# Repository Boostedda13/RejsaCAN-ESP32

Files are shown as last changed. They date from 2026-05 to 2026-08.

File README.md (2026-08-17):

# RejsaCAN

RejsaCAN is a 3x5 centimetre small ESP32 or ESP32-S3 based board aimed at car use that I put together for my own use in my assorted crazy car projects. The board has an onboard CAN interface and can be powered directly from the car (5-24V). It also includes the option to auto shutdown so not to drain the car battery. This is especially important if you have it plugged in to a car OBD2 connector since these always supply constant 12V power to the connector, even when the car is parked and turned off.

There is no bespoke code for the board apart from pin definitions, it's just a piece of universal hardware, but by using easy to use open source Arduino libraries it can be made to interface not only to various CAN buses, Network/Wifi and Bluetooth but to numerous sensors and other peripherals using the ESP32's built in interfaces.

You can assemble your own board if you want, you find schematics, Gerber files and bill of materials in the <a href=Schematics>schematics folder</a>. I currently have a few extra boards so if you need one or more factory assembled boards you can always contact me at magnust@gmail.com.
  
### Nice review and get started guide at cnx-software  
  
https://www.cnx-software.com/2023/05/12/rejsacan-esp32-s3-can-bus-board-arduino-car-hacking/  
  
### Navigate  
  
- <a href=./>Main page (this page)</a>  
 
- <a href=Projects%20and%20ideas>Fun projects and ideas</a>  
 
- <a href=Schematics>Schematics</a>

- <a href=Code%20Examples>Code examples</a>
 
- <a href=Tips%20to%20setup%20IDE%20and%20get%20started>Links to some different CAN libraries and tips to get started</a>  
  
-  <a href=3dprint>Examples of 3D printable housings</a>  

-  <a href=Auxiliary%20boards>Some odd auxiliary boards I made to mount an OBD2 connector, display, thermal cam...</a>  

<hr>
  


## Pinout  
  
See complete pinout.h https://github.com/MagnusThome/RejsaCAN-ESP32/blob/main/Schematics/

S3 rear

## Schematics

click to get full schematics



## The board is based around an ESP32 or ESP32-S3 chip

The ESP32-S3 is a very nice and capable chip that supports a mind boggling range of different communication standards and hardware auxiliaries making it a very versatile "hub" for shuffling data between different systems.  

- SPI bus
- I2C bus
- BLE (Bluetooth 5)
- Wifi (both as AP or client)
- Networking, everything from simple http, mqtt, ajax, ntp to running a full webserver on it with a user interface
- USB port (serial in/out and also OTG as virtual keyboard, wireless storage...)
- Analog input, PWM or analog output

## Examples

- Read CAN data and send back CAN packets to control the car (set to sport mode as default, lock doors when driving away, this is one of my current projects)
- CAN to BLE or network/Wifi bridge
- CAN interface for sniffing CAN bus with for example SavvyCAN
- Read I2C/SPI/analog sensor data and write to CAN bus for CAN bus based data loggers
- Publish live telemetric data on internet from Racechrono (I'm starting this project now)
- Drive alarm beeper or LED to show status of CAN data (like my small project Money Shift Saver and also low oil pressure warning)
- Drive high power peripherals using a driver board
- Translate CAN data between two CAN buses (like my small project Current Gear HUD here on github)

- I have already made a connector board to attach the RejsaCAN on the back of the commonly available small ILI9341 touch screen.

## Ideas for peripherals



- IR camera sensor arrays (MLX90xxx or AMG8833) to log tire, brake, drivetrain temperatures over BLE to Racechrono or CAN based loggers (like my project RejsaRubberTrac https://github.com/MagnusThome/RejsaRubberTrac)  
- Laser based TOF distance sensor to log suspension travel (I did this too with RejsaRubberTrac)  
- SPI or I2C based color displays to show CAN bus data like IC intake or oil temps or alarms  
- SPI or I2C based color displays to show live telemetric data fetched over BLE from Racechrono  
- A second CAN port  
- Driver board to drive high power items  
- Step motor drivers  
- Multiple input analog or digital boards  
   
## One of the 3D printed housings with OBD2 connector I've made


## Or just the board and screw terminals


# CAN interface

You can hook the board up straight to the car's OBD2 port or attach it directly to any CAN bus. You just need to connect the four wires. 12V power, ground, CAN high and low. There is of course a bus termination resistor on the board, it can be disabled if not needed by cutting a pcb trace and optionally mounting a pin header and jumper.

# Supply requirements (v3.5)

**Feed this board from a fused accessory circuit downstream of the vehicle's own
load-dump suppression. Do not hard-wire it upstream of a battery master / kill switch.**

That is not boilerplate, it is the condition the front end is designed to. The board is
rated **5-24 V** with a 33 V DC ceiling, which covers a 12 V system running at 14 V,
a 24 V jump start for 60 s, regulator failure at 18 V for 60 min, reverse polarity, and
ISO 7637-2 pulses 1, 2a, 3a and 3b. The clamp is a 33 V bidirectional TVS at the
connector, so a *suppressed* load dump (35 V for up to 400 ms, which is what a modern
alternator produces) is survived on voltage rating alone.

An **unsuppressed** load dump is a different event: 79-101 V for 40-400 ms, carrying
20-52 J. Opening a battery master switch with the engine running produces exactly that.
No discrete TVS of any package size absorbs it -- a 3 kW SMC part is worth about 3 J.
Surviving that case needs a series surge stopper (LTC4364 class) and roughly 150 mm2 of
board this design does not have. Since RejsaCAN is aimed at motorsport, where kill
switches are common, this restriction is the trade that was made deliberately.

24 V *systems* are out of scope. Their suppressed load dump is 58 V, which no clamp
below 58 V standoff survives, and a 60 V standoff part clamps near 97 V.

# Functionality

The idea was to make an as small as possible CAN + ESP32 board with as many cool and useful "good to have" functions as possible included. You know as well as I do that when tinkering around you suddenly get a new idea and need x or y :-D 

## Auto shutdown

When the engine is running and charging the car battery the incoming voltage used to power the board is a little bit higher than when the engine is stopped. This can be used to automate board shutdown so not to drain the car battery. As default the on board DC-DC power circuit will shutdown the whole board when the power voltage is below the "engine is running" threshold and boot up the board when it is above. But you can run the board in a number of other ways too, for example using ESP32 sleep mode, waking it and putting it to sleep depending on CAN traffic, voltage level from the car, delays and so on.

- An output (FORCE_ON GPIO17) can be pulled high to keep the board running even if the car voltage drops below the threshold (instead of disabling the auto shutdown fully on the pcb by shorting the "ALWAYS ON" bridge). The ESP32 can keep this pin high even during sleep.

- A digital input (SENSE_V_DIG GPIO08) monitors if the car voltage is above or below the "engine running" threshold. This can both be used to trigger waking the board from sleep or just as a simple check if the engine is charging the car battery or not.  

- The voltage from the car can be monitored using analog input (SENSE_V_ANA GPIO9) to check not only charging level but also battery discharge level when parked, health of charging, health of battery, detect large loads being switched on or off in the car and so on.

- The CAN data input (CAN_RX GPIO13) can also be used to trigger waking up the board from sleep as soon as CAN traffic is detected.

Either one can just let the board turn on and off with the auto shutdown hardware circuitry straight out of the box or you can run it in combination with software. For example, when the car voltage rises and the board boots you can pull FORCE_ON high to make sure the board keeps running even if there is a drop of voltage, for example due to red light start/stop functionality in the car or modern cars turning down battery charging even when driving. Then you just monitor either the threshold with SENSE_V_DIG or set your own thresholds using SENSE_V_ANA and then add your own timer delays or whatever. And of course, you can use CAN to check if the car is stopped in a multitude of ways, rpm, speed, gear...

### Fine tuning on/off voltage thresholds  

If your car has a more modern battery type than the old acid/led type or if it does the battery charging slightly different you might want to adjust the on/off voltage thresholds. If you keep R5 as 33k and adjust R4 you can get these switch-on and -off voltages:

| **R4** | **Turn on at** | **Turn off at** |
|---:|---:|---:|
| 91k | 13,7V | 13,0V |
| 90k | 13,6V | 12,9V |
| 89k | 13,5V | 12,8V |
| 88k | 13,4V | 12,7V |
| 87k | 14,3V | 12,6V |
| 86k | 13,2V | 12,5V |
| 85k | 13,1V | 12,4V |

### 24V vehicles

For 24V vehicles you can change the on/off voltage threshold by soldering on a resistor at the empty "ADJUST" position. I don't know what voltages one can expect in these vehicles while charging and not charging the battery so I have no idea what an appropriate resistor value should be there. 

matrix power scenarios  

## "Good to haves"

### Three on board LEDs  

- Green power LED that shows if the board is turned on or not. If using the auto shutdown the green LED (and the board) will be turned on and off depending on if the car voltage is over or under the auto start/shutdown threshold.

- Blue LED to use for anything you fancy (BLUE_LED GPIO10) (this one is red on some boards due to the blue led being out of stock lately)
- Yellow LED to use for anything (YELLOW_LED GPIO11)

### Extra UART RX/TX

The ESP32-S3 has a built in USB port for uploading firmware, OTG support(!) and general communication. But on the board's rear there are breakout pads for a second UART (TXD0 and RXD0) so you can use this as a serial port and the board's USB port for other tasks like JTAG or OTG, acting as a peripheral keyboard, mouse, wireless storage and so on.

### 3V3 HIGH DRIVER

The GPIO pins on the ESP32-S3 can, in addition to general digital circuitry, also drive 10-20mA loads like LEDs and other smaller loads. But on the RejsaCAN board there is an added more powerful driver circuit that can drive slightly larger loads of a few hundred mA at 3,3V. This can be used for different things like powering external sensors or a small display that you want to be able to shutdown fully to minimize power consumption while in sleep mode for example. This 3V3_SWITCHED output is controlled by HI_DRIVER (GPIO21). The ESP32-S3 can keep this on or off when in sleep mode.

There is also a 3,3V power output pad in the row of connection pads on the board that is turned on whenever the board is running. Keep in mind that this is _not_ a 3V3 input to drive the board, it is only an output to drive external I2C, SPI and other sensors.

### SD card reader

The ESP32-S3 has an SD micro card reader on the rear of the pcb. It is connected to SPI and select SD_CARD (GPIO45)

### Other general IO pins
  
All the GPIOs found on the row of connector pads are general purpose. They can be PWM, analog, digital in/out whatever, special protocols driving or reading most things you can think of. But for ease of use for me with occasional lousy memory I have marked some default uses:  
  
I2C SDA  (GPIO1)  (A0)  
I2C SCL  (GPIO2)  (A1)  
GND  
3V3  
  
SPI MISO / MTDI  (GPIO41)  
SPI CLK  / MTCK  (GPIO39)  
SPI MOSI / MTDO  (GPIO40)  
  
General  (GPIO12)  
General  (GPIO48)  
General  (GPIO47)  
High driver switched output max 500mA  (GPIO21)  

On the rear side of the pcb you can get to a few extra pins but it's not possible to solder pin headers here due to the esp-module being on the other side of the board where these pads are.  
  
General  (GPIO6)  (A5)  
General  (GPIO7)  (A6)  
General  (GPIO15)  
General  (GPIO16)  
MTMS  (GPIO42)  
PROG  (GPIO0)  
JTAG_ENABLE  (GPIO3)  
TXD0   
RXD0  

### CAN bus

As mentioned earlier the CAN_RX (GPIO13) can wake the ESP32-S3 from sleep whenever any traffic is seen on the CAN bus.

To minimize power draw when not using the CAN bus, for example not listening to the bus to detect traffic to wake the ESP32 from sleep mode, the CAN transceiver can be put in standby mode by pulling CAN_RS (GPIO38) high. The ESP32-S3 can keep this pin high even when in sleep mode reducing the complete boards power draw to an absolute minimum.

The rise time of the CAN transceiver chip can be changed pulling CAN_RS (GPIO38) low. Default is keeping the pin unmodified in high impedance state for an optimal not-to-fast rise time setting. See specs for the transceiver chip SN65HVD230DR.

### JTAG

You can either run JTAG over the USB port or optionally keep the USB port free by connecting your JTAG hardware to MTDI, MTDO, MTCK and MTMS on the board. Note that MTMS is only available on the board's rear. The other are available in the row of connecting pads. Incidentally the MTDI, MTDO and MTCK are the same as the SPI default pins.

To enable JTAG mode you need to pull the JTAG_ENABLE pad, found on the rear of the board, high or low at boot.

### Board version

On v3.x boards you can programmatically check what version of the board your code is running on and adjust accordingly for the small changes that have been made on the boards. Set GPIO4 and GPIO5 to input pullup and check if the inputs are high or low.

- v3.1 = GPIO4 low and GPIO5 high  
- v3.2 = GPIO4 high and GPIO5 low  

### Changes

#### from v3.1 to v3.2

- Added RS control of the CAN chip to set both standby mode and faster rise times
- Added better over voltage protection on power from the car
- Upgraded over voltage protection on USB power
- Enabling ALWAYS_ON is now done by shorting two clearly marked pads on the rear of the board
- An added empty spot for resistor R19 ADJUST which can be added to lower the start/stop voltage threshold for the board
- For panic situations when you need more pins ;-) the GPIO6, GPIO7, GPIO15 and GPIO16 are available as unmarked pads but only on the rear of the board
  
#### From v2.3 to v.2.4
  
- Upgraded over voltage protection on USB power  

#### From v2.4 to v.2.5 and 3.2 to 3.3
  
- DC-DC converter supports 24V input. The auto switch on/off threshold can be changed by changing two resistor values.  

## Power consumption  
 
At 14V the complete board draws *on average* roughly:  
- Bluetooth turned on but no connections = 16mA (+ 4mA for power LED)
- Wifi turned on as AP with local web server but no connections = 46mA (+ 4mA for power LED)
- No wifi or Bluetooth = 14mA (+ 4mA for power LED)
- Sleep = 3mA (+ 4mA for power LED). Note that the CAN transceiver is fully active and the DC-DC buck converter probably has some idle draw also.
- Sleep and CAN transceiver put in standby = hmmm, must test this, a fraction of a mA is my guess.
   
## Housing

Check out 3D printable housings in the <a href=3dprint>the 3D-print directory</a>. So far I've made one housing where you connect using a cable and another one with an integrated OBD2 connector to plug directly into the car.



transparent-case-1

small-housing(0)
  


## Connecting the board

When not using the housing with an integrated OBD2 connector or the screw terminals as seen in the picture above I've used a widely available OBD2 splitter cable (flat cable) that has one male and two female connectors. I hook up the male connector to the car, cut off one female connector and wire the remaining pig tail cable into the RejsaCAN board and one female connector is then free for other equipment to hook up to the car.

Picture showing what wires to use but please measure your cable and don't trust all these splitter cables to be 100% identical. (the second female splitter connector is not visible in pic)
   
OBD2 splitter pinout
 
small-housing(3)
 
small-housing(2)

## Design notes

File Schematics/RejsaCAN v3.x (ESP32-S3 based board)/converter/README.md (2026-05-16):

# EasyEDA Standard → Fusion/Eagle 9.x converter

Custom converter built to translate the RejsaCAN v3.4 EasyEDA Standard
schematic (`RejsaCAN v3.4 - Schematic.json`) into a Fusion-importable
Eagle 9.x `.sch` file. Fusion Electronics has no native EasyEDA
importer; the official-blessed paths (EasyEDA → Altium → Fusion, or
EasyEDA → KiCad) all failed in different ways, so we built this.

## Files

| File | Purpose |
|---|---|
| `easyeda_parser.py` | Parses the tilde/caret/hash-encoded EasyEDA JSON into clean Python dataclasses; also resolves nets via union-find and splits wires at T-intersections. |
| `eagle_emitter.py` | Synthesises an Eagle 9.x XML schematic (library + parts + sheet + nets) from the parsed structure. |
| `convert.py` | CLI: `python convert.py <input.json> [-o output.sch] [--summary]` |

Run from this `converter/` directory:

```
python convert.py "..\RejsaCAN v3.4 - Schematic.json" -o "..\RejsaCAN v3.4.sch"
```

## EasyEDA Standard JSON format (reverse-engineered)

The schematic file is a JSON wrapper around a list of "shape" strings,
each tilde-delimited. Multi-piece shapes use `#@$` between sub-pieces
and `^^` between sub-fields within a piece.

Top-level structure:
```
{
  "editorVersion": "6.5.39",
  "docType": "5",
  "title": "...",
  "schematics": [
    {
      "dataStr": {
        "shape": [ "<shape1>", "<shape2>", ... ]
      }
    }
  ]
}
```

### Shape prefixes seen in this file

| Prefix | Count | Meaning |
|---|---|---|
| `LIB` | 66 | Component instance (incl. 1 page-frame instance) |
| `W` | 144 | Wire polyline (`W~x1 y1 x2 y2 [x3 y3 ...]~color~...`) |
| `J` | 74 | Junction dot (`J~x~y~radius~color~gid~lock`) |
| `F` | 90 | Net label / flag (anchor + text + decoration) |
| `O` | 11 | No-connect marker (X-shape glyph at a coord) |
| `T` | 2 | Free text annotation |

### LIB (component) internals

A LIB shape has the header followed by `#@$`-separated sub-pieces:
```
LIB ~ x ~ y ~ propBlob ~ rotation ~ importFlag ~ uuid ~ ...
  #@$ T~P~...~designator~...     (designator)
  #@$ T~N~...~value~...           (value/name)
  #@$ R~bx~by~bw~bh~...           (body rectangle, decorative)
  #@$ P~display~elec~pinNum~px~py~rot~gid~lock^^portX~portY^^pathDef^^pinNameField^^pinNumField^^...
  #@$ ... (more pins)
```

**propBlob** is backtick-delimited key/value pairs:
```
package`HDR-M-2.54_1X2`Supplier Part`C124375`Supplier`LCSC`...`
```

**Pin** sub-piece pieces (joined by `^^`):
1. Header: `P~show~0~<pinNum>~<x>~<y>~<rot>~<gid>~<lock>`
2. Port: `<portX>~<portY>` — **this is the wire-attach coordinate**
3. Path: `M ... h ...` — pin line drawing
4. Pin name field: `1~<x>~<y>~0~<text>~start~~~<color>`
5. Pin number field
6. Optional clock/dot decorations

### F (net label) internals

```
F~part_netLabel_<style>~<x>~<y>~<rot>~<gid>~~<lock>
  ^^<anchorX>~<anchorY>
  ^^<netName>~<color>~<textX>~<textY>~...~<flag_id>
  ^^PL~<polyline...>  (label flag graphics, decoration only)
  ^^...
```

The **net name** is the first sub-field of the third `^^`-piece. The
**anchor** in the second piece is the connection point (where the flag
"points to").

### Coordinate system

EasyEDA Standard uses **10-mil units** (1 unit = 0.254 mm) with **Y
positive-down**. Eagle uses millimetres with Y positive-up. Conversion:

```
eagle_mm_x = easyeda_x * 0.254
eagle_mm_y = -easyeda_y * 0.254
```

The 1149 × 806 sheet frame is exactly A4 (291.85 × 204.72 mm) at this
scale.

## Architecture

### Stage 1 — parse → intermediate

`easyeda_parser.parse(path)` returns an `EasyEDASchematic`:

```python
@dataclass
class EasyEDASchematic:
    title: str
    parts: list[Part]              # 65 components (page frame stripped)
    wires: list[WireSegment]       # 247 segments after T-intersection split
    junctions: list[Junction]      # 74 junction markers
    labels: list[NetLabel]         # 90 named-net labels
    no_connects: list[NoConnect]   # 11 NC markers
    pin_to_net: dict[(des, pin#), net_name]
    nets: dict[net_name, list[(des, pin#)]]
    wire_to_net: dict[wire_idx, net_name]
```

Net resolution uses **union-find on coordinate keys** (quantised to
0.01 EasyEDA units). All connection points (pin ports, wire endpoints,
junction coords, label anchors) get added; wires union their two
endpoints; labels with the same name across disjoint clusters union
those clusters (named global nets like `GND`, `+3V3`).

### Stage 2 — emit Eagle 9.x XML

For each part: synthesise one symbol + one deviceset (no dedupe in v1;
65 unique symbols/devicesets, no package mapping). Then emit a single
sheet with instances + nets.

### Net partitioning

A single Eagle `<net>` may contain multiple `<segment>` elements; each
segment must be a graph-connected wire group. Bridging across
segments happens via shared label name. The emitter does its own
union-find per net (over wire endpoints only — labels do **not** bridge
segments) and emits one `<segment>` per connected component, attaching
pinrefs / labels / junctions to whichever component contains their
coord.

## Bugs we hit and fixes

These are the gotchas, in order of severity, all encountered while
iterating against Fusion's ERC. Document them so future-you doesn't
re-discover them.

### 1. T-intersection blindness (catastrophic)

EasyEDA freely allows a wire's endpoint to terminate in the **middle**
of another wire's segment, marked with a junction dot. My initial
union-find merged only on exact endpoint equality, so it missed every
T-intersection — fragmenting what should be one net into many. **Net
count dropped from 100 → 63 once T-splitting was added.**

Fix: `_split_wires_at_intersections()` in `easyeda_parser.py`. For
every wire, find any "interesting" coord (other wire endpoints,
junctions, pin ports, labels) lying on its interior, and replace the
wire with multiple sub-segments through those points. Restricted to
axis-aligned wires (EasyEDA schematics are virtually always
axis-aligned).

### 2. "Segment of net X has fallen apart" (37 errors)

First-pass emitter dumped all wires of a net into one
`<segment>`. Eagle requires each segment to be a graph-connected wire
group. Fix: `_emit_partitioned_nets()` runs union-find per net (over
wires only, not labels) and emits one segment per component.

### 3. Labels attached directly to pins ("floating pinref")

EasyEDA permits a net label flag to attach directly to a pin's port
with no explicit wire drawn. Eagle considers a pinref "floating" if
its coord has no wire endpoint, junction, or sibling pin
there. Fix: emit a 1.27 mm stub wire from each label-only-attached
pinref's coord into space (always +x direction; cosmetic-only).

### 4. Missing junction at pin + 2 wires meeting

Eagle's "missing junction" warning fires not just for 3+ wire endpoints
meeting, but also for **1 pin + 2 wire endpoints** meeting at a coord
(visually a T at the pin). Fix: junction emission rule is
`(wire_endpoints + pinref_count) >= 3 OR pinref_count >= 2`. The
second clause also handles direct pin-on-pin overlaps (the
`R10.1+R9.1`, `R15.1+YELLOW.2`, etc. cases).

### 5. Junctions created from EasyEDA coords were under-emitted

Initial logic only emitted junctions where EasyEDA originally had
one. After T-splitting, **new** multi-endpoint coords appear that
EasyEDA never marked (they were on the interior of a wire before
splitting). Fix: emit junctions self-driven from the segment's wire
endpoint counts, not from `c["juncs"]`.

### 6. Synthesised body boxes colliding with neighbours

For parts where all pins lie on a single axis (most 2-pin SMDs, header
strips, the 13-pin SD-CARD, the 16-pin USBC), the original "body" was
some EasyEDA glyph in a particular position. Our placeholder
rectangle, placed perpendicular to the pin line, ended up overlapping
neighbour parts' pins on the sheet. This triggered "Net X overlaps
pin" / "Pins overlap" warnings.

Fix tried in stages:
- Shrink degenerate-axis body to 1.27 mm thickness — reduced collisions but didn't eliminate edge-touches.
- Drop body wires entirely for degenerate-axis parts (59 of 65) — eliminates warnings but loses cosmetic body shape.
- Switch all pin lengths from `short` (2.54 mm) → `point` (0 mm) — pins can no longer extend to overlap anything.

### 7. Pin rotation pointing into colinear neighbours

For multi-pin colinear parts (SD-CARD's 13 pins all at same x), the
original `infer_pin_rot` used pin-bbox centre — which equalled each
pin's x — so adjacent pins got opposite vertical rotations and their
drawn stubs hit each other's connection points. Fix:
`infer_pin_rot_from_body` chooses rotation by the body edge each pin
is closest to (or outside of), so all pins on one face of a body
rotate the same way.

### 8. Eagle name strictness

Designators like `SD-CARD` (hyphen) and all-caps descriptive names
like `BLUE`, `POWER`, `GPIO`, `I2C` were preserved per user request.
Fusion 9 accepted them all; if a future version of Eagle/Fusion
rejects, run them through `sane_name()` with a stricter character set.

## Final state

- 65 parts, 63 nets, 117 segments, 67 junctions, 534 wires (incl. body
  wires for the 6 chip-style parts and synthesised stubs).
- ~22 ERC warnings remaining, all by design:
  - **19 single-pin nets** — 11 are EasyEDA NC markers (intentional);
    8 are named ESP32 pins not broken out in this design (GPIO6/7/15/16,
    JTAG_ENABLE, MTMS, RXD, TXD). Approve in Fusion's ERC.
  - 0–3 residual cosmetic edge cases.

## Limitations / known cosmetic issues

- **Symbol art is placeholder.** Passives show as connection points
  only (no zigzag/plate). Multi-axis-spread chips show as bounding
  rectangles. Connectivity is correct; cosmetics need manual library
  swap if visual fidelity matters.
- **No PCB output** (`.brd`). The deviceset has no package mapping —
  every part is "schematic-only". Forward-annotate from Fusion to a
  new board if you want to lay out.
- **No multi-sheet support.** Source file has 1 sheet; multi-sheet
  parsing exists in `parse()` but the emitter ignores sheets > 0.
- **NCs handled as single-pin nets**, not Eagle no-connect markers
  (Eagle 9 has no first-class `<no_connect>` element — the standard
  workaround is just an unconnected pin).
- **Stub wires are always +x direction** for label-only-attached pins.
  Could be cosmetically improved by aiming toward where the label
  text sits.

## Future work

If anyone needs to extend this:

- **KiCad emitter** as a peer to `eagle_emitter.py`. The intermediate
  `EasyEDASchematic` is format-agnostic; KiCad's S-expression schema
  is simpler than Eagle's XML. ~1 hour of work.
- **Symbol dedupe.** Currently 65 unique symbols/devicesets. A
  componentUuid-based key would collapse duplicates (all R0402s share
  one symbol).
- **Real symbol art.** Parse the `R~`, `PT~` (path), `PL~` (polyline),
  `E~` (ellipse) sub-pieces inside each LIB and emit as Eagle wire/
  arc/circle elements within the symbol.
- **Package mapping.** Devicesets currently have no `<package>`
  element. Adding a stub package per part (with pad numbers matching
  pin numbers) would enable forward-annotation to a board.
- **Multi-sheet** when source has > 1 sheet.
- **Bus support.** EasyEDA buses (B-prefix shapes) are not handled.
  This file has no buses so it didn't matter.

## Quickstart for the next person

```bash
cd "Schematics/RejsaCAN v3.x (ESP32-S3 based board)/converter"
python convert.py "../RejsaCAN v3.4 - Schematic.json" --summary
# writes ../RejsaCAN v3.4.sch and prints parts + top nets
```

Open the resulting `.sch` in Fusion Electronics 9.x. Run ERC. Approve
the by-design single-pin warnings. Edit freely.

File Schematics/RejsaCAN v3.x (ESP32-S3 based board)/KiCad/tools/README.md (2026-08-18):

# tools/

Scripts that finished the v3.5 board without the GUI. They run under KiCad's own Python
(`"C:\Program Files\KiCad\10.0\bin\python.exe"`, the only interpreter with `pcbnew`) and operate on
`../RejsaCAN v3.4 - Schematic.kicad_pcb`. Scratch output goes to `tools/out/` (gitignored) or to
`$REJSA_OUT`.

| Script | What it does |
|---|---|
| `miniroute.py NET [--w 0.2] [--via 0.6/0.3] [--layers F,I2,B] [--window x0 y0 x1 y1] [--viacost 120] [--src REF.PAD --dst REF.PAD] [--apply]` | Obstacle-aware grid router for **one connection**: rasterises every copper item that is not on `NET` into per-layer masks inflated by `w/2 + max(clearance of both net classes) + 1 cell`, plus a via mask (all layers, hole-to-hole, edge band), then runs Dijkstra from the smallest island of the net to the largest over F/In2/B with via transitions. Without `--apply` it only writes `<tag>_path_<layer>.png` overlays. With `--apply` it adds the copper, snaps route ends to pad centres, refills zones and keeps a `.bak`. Run it repeatedly for a net with more than two islands. |
| `stitch.py [--grid 4.0] [--minsp 1.2] [--via 0.6/0.3] [--apply]` | GND stitching vias: a fence both sides of the RF trace, a ring around U7's ground pads, and a grid — every candidate filtered by the router's via mask and by outer-layer pour membership, then added all at once so DRC can prune. |
| `drcgate.py TAG [--show type1,type2]` | `kicad-cli pcb drc --severity-all --all-track-errors`, summarised as error/warning counts by type plus the unconnected list. **This is the acceptance test**: apply one change, run it, keep the change only if errors did not rise. |

The router is deliberately not a full autorouter: it knows nothing about the `.kicad_dru` custom
rules beyond net-class clearance, it does not shove, and it will happily route the last connection
through an ugly place if that is the only free one. It exists because the interactive router needs a
GUI session and Freerouting cannot be told to finish a nearly-complete board (see CLAUDE.md).

Things learned the hard way, all encoded above:

- `NETINFO_ITEM.GetNetClass()` returns a bare `SwigPyObject`; use `GetNetClassName()` and read the
  clearance table from the `.kicad_pro` JSON. Getting this wrong routed Battery-class copper at
  0.15 mm and produced 11 clearance errors.
- PIL rasterises to integer pixels, so a shape can end up half a cell short — hence the extra cell of
  inflation. Without it one route landed 0.01 mm inside a pad's clearance.
- A track hugging the board edge leaves a hair-thin GND pour strip outside it (`connection_width`
  0.0004 mm); the edge band keeps tracks ≥ 0.85 mm from the outline so the strip is a real pour or
  nothing.
- Route ends are snapped to pad centres. KiCad's connectivity is shape-based and accepts a track
  ending on a pad edge, but it looks like a mistake and is fragile.

## Schematic tools

The same idea applied to the `.kicad_sch`, used to reorganize the schematic on 18 Aug 2026:

| Script | What it does |
|---|---|
| `schgeom.py` | Parses the schematic (own S-expression parser), builds symbol bounding boxes from `lib_symbols`, pins, labels, wires, visible field texts (real font size + justify), and prints an overlap report. |
| `schclusters.py` | Wired clusters — symbol + wires + labels + junctions joined by geometry. Anything translated as a cluster keeps its connectivity. |
| `schmove.py --apply` | Rigid cluster moves to a target table, editing only the `(at ..)`/`(xy ..)` numbers inside each node's text span (file otherwise byte-identical). |
| `schfix2.py`, `schfix3.py` | The two hand fixes of that pass (label re-pointing; J1's GND flag on a longer wire). |
| `schtext.py --apply` | Auto-placer for Reference/Value texts that collide with symbols, labels or other texts. |
| `netcheck.py save <tag>` / `compare <a> <b>` | **The acceptance test**: `kicad-cli sch export netlist` reduced to pin-groupings, compared before/after (net renames reported separately). Also diff `kicad-cli sch erc` counts. |

Traps met: scripted symbols carry `(unit 0)` — KiCad draws every unit's pins for those; KiCad 10 writes
`(hide yes)` at *property* level, not inside `effects`; EasyEDA-imported fields are 1.69 mm Arial,
left-justified — model both or the placer puts "D10" on top of its own value.

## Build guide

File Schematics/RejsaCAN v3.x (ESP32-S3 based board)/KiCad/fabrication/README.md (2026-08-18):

# fabrication/

Generated manufacturing output for the KiCad board — Gerbers, drill files, position files, BOM
export, renders, STEP. **Nothing in here is a design source.** Everything is reproducible from
`../RejsaCAN v3.4 - Schematic.kicad_pcb`, so the contents are gitignored and only this README is
tracked.

Regenerate without opening the GUI (4-layer set with Protel extensions, which is what JLCPCB expects;
`RejsaCAN_v3.5_gerbers.zip` is the upload):

```bash
cd "Schematics/RejsaCAN v3.x (ESP32-S3 based board)/KiCad"
kicad-cli pcb export gerbers -o fabrication/gerbers/ \
  --layers F.Cu,In1.Cu,In2.Cu,B.Cu,F.Paste,B.Paste,F.Silkscreen,B.Silkscreen,F.Mask,B.Mask,Edge.Cuts \
  --subtract-soldermask --no-x2 --disable-aperture-macros "RejsaCAN v3.4 - Schematic.kicad_pcb"
kicad-cli pcb export drill -o fabrication/gerbers/ --format excellon --drill-origin absolute \
  --excellon-units mm --excellon-zeros-format decimal --excellon-separate-th "RejsaCAN v3.4 - Schematic.kicad_pcb"
kicad-cli pcb export pos -o fabrication/cpl.csv --format csv --units mm --side both --smd-only "RejsaCAN v3.4 - Schematic.kicad_pcb"
kicad-cli pcb render -o fabrication/render_top.png --side top --background opaque --quality basic --width 2400 --height 1900 "RejsaCAN v3.4 - Schematic.kicad_pcb"
kicad-cli pcb render -o fabrication/render_iso.png --perspective --rotate "-35,0,25" --floor --quality high --background opaque --width 2400 --height 1600 "RejsaCAN v3.4 - Schematic.kicad_pcb"
kicad-cli pcb export step --subst-models --force -o fabrication/RejsaCAN_v3.5.step "RejsaCAN v3.4 - Schematic.kicad_pcb"
```

Render notes: `--quality high` in the orthographic top/bottom views paints the board's own drop shadow
onto the floor beside it, which reads as a ghost outline — use `basic` for those and keep `high` for
the perspective view. U7 (LG290P03), J1 (Micro-Fit), USBC1 and SD-CARD1 have no 3D models and render
as pads/outlines.

Upstream's released output for the *fabricated* board is a different thing and lives one directory up
as `RejsaCAN v3.4 - Gerber.zip`. Don't confuse the two: that zip is the board that physically exists,
this directory is whatever the KiCad project currently produces.

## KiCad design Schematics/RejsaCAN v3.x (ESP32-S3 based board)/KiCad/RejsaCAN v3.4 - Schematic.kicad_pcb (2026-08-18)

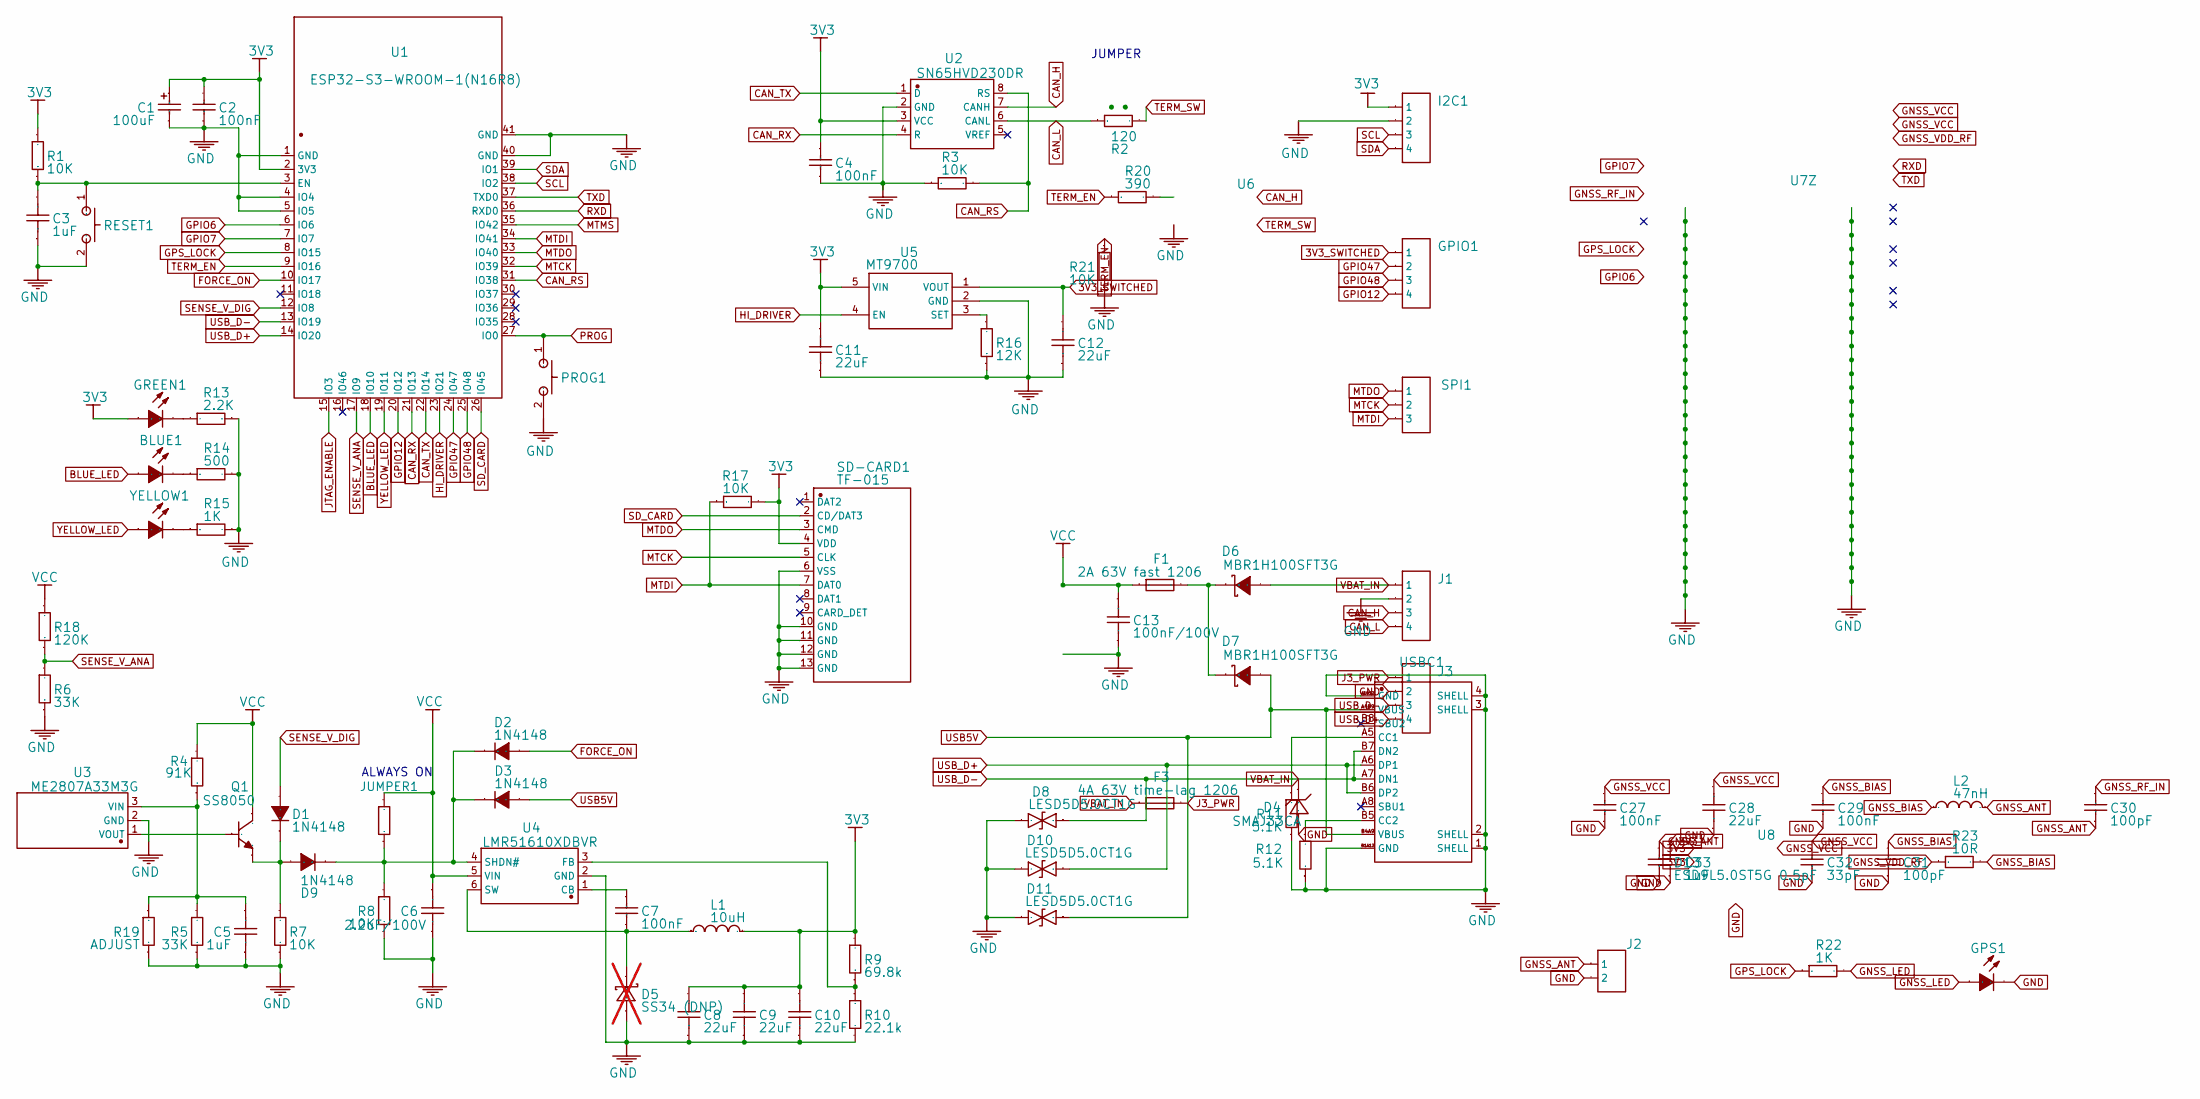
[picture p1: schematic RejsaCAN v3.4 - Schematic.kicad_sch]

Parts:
BLUE1: 19-217/BHC-ZL1M2RY/3T; LED_0603_1608Metric; Manufacturer Part 19-217/BHC-ZL1M2RY/3T
C1: 100uF; CP_EIA-3528-21_Kemet-B; Manufacturer Part TAJB107K006RNJ
C2, C4, C7, C27, C29: 100nF; C_0402_1005Metric; Manufacturer Part CL05B104KO5NNNC
C3, C5, C33: 1uF; C_0402_1005Metric; Manufacturer Part CL05A105KA5NQNC
C6: 2.2uF/100V; C_1210_3225Metric; Manufacturer Part CL32B225KCJSNNE
C8, C9, C10, C11, C12, C28: 22uF; C_0603_1608Metric; Manufacturer Part CL10A226MQ8NRNC
C13: 100nF/100V; C_0603_1608Metric; Manufacturer Part CL10B104KC8NNNC
C30, C31: 100pF; C_0402_1005Metric; Manufacturer Part 0402CG101J500NT
C32: 33pF; C_0402_1005Metric; Manufacturer Part 0402CG330J500NT
D1, D2, D3, D9: 1N4148; D_SOD-323; Manufacturer Part 1N4148WS
D4: SMAJ33CA; D_SMA; Manufacturer Part SMAJ33CA
D5: SS34 (DNP); D_SMA; Manufacturer Part SS34; not fitted
D6, D7: MBR1H100SFT3G; D_SOD-123F; Manufacturer Part MBR1H100SFT3G
D8, D10, D11: LESD5D5.0CT1G; D_SOD-523; Manufacturer Part LESD5D5.0CT1G
D13: ESD9L5.0ST5G 0.5pF; D_0402_1005Metric; Manufacturer Part ESD9L5.0ST5G
F1: 2A 63V fast 1206; Fuse_1206_3216Metric; Manufacturer Part 0466002.NRHF
F3: 4A 63V time-lag 1206; Fuse_1206_3216Metric; Manufacturer Part 1206T4A63V
GPIO1: HDR-M-2.54_1x4; PinHeader_1x04_P2.54mm_Vertical; Manufacturer Part B-2100S04P-A110
GPS1: Blue LED; LED_0603_1608Metric; Manufacturer Part 19-217/BHC-ZL1M2RY/3T
GREEN1: 19-217/GHC-YR1S2/3T; LED_0603_1608Metric; Manufacturer Part 19-217/GHC-YR1S2/3T
I2C1: HDR-M-2.54_1x4; PinHeader_1x04_P2.54mm_Vertical; Manufacturer Part B-2100S04P-A110
J1: Micro-Fit 3.0 4P R/A; Molex_Micro-Fit_3.0_43045-0400_2x02_P3.00mm_Horizontal; Manufacturer Part 43045-0400
J2: U.FL; U.FL_Hirose_U.FL-R-SMT-1_Vertical; Manufacturer Part U.FL-R-SMT-1(10)
J3: JST-XH 4P LTE; JST_XH_B4B-XH-A_1x04_P2.50mm_Vertical; Manufacturer Part B4B-XH-A(LF)(SN)
JUMPER1: -; R_0402_1005Metric; Manufacturer Part DNP
L1: 10uH; L_Sunltec_SLP6028S_6.0x6.0mm; Manufacturer Part SLP6028S100MTT
L2: 47nH; L_0402_1005Metric; Manufacturer Part LQW15AN47NJ00D
PROG1: GT-TC029B-H025-L1N; SW_Push_GSwitch_GT-TC029B; Manufacturer Part GT-TC029B-H025-L1N
Q1: SS8050; SOT-23; Manufacturer Part SS8050
R1, R3, R7, R8, R17, R21: 10K; R_0402_1005Metric; Manufacturer Part 0402WGF1002TCE
R2: 120; R_1206_3216Metric; Manufacturer Part RTT061200FTP
R4: 91K; R_0402_1005Metric; Manufacturer Part 0402WGF9102TCE
R5, R6: 33K; R_0402_1005Metric; Manufacturer Part 0402WGF3302TCE
R9: 69.8k; R_0402_1005Metric; Manufacturer Part 0402WGF6982TCE
R10: 22.1k; R_0402_1005Metric; Manufacturer Part 0402WGF2212TCE
R11, R12: 5.1K; R_0402_1005Metric; Manufacturer Part 0402WGF5101TCE
R13: 2.2K; R_0402_1005Metric; Manufacturer Part 0402WGF2201TCE
R14: 500; R_0402_1005Metric; Manufacturer Part 0402WGF4700TCE
R15, R22: 1K; R_0402_1005Metric; Manufacturer Part 0402WGF1001TCE
R16: 12K; R_0402_1005Metric; Manufacturer Part 0402WGF1202TCE
R18: 120K; R_0402_1005Metric; Manufacturer Part 0402WGF1203TCE
R19: ADJUST; R_0402_1005Metric; Manufacturer Part 0402WGF9102TCE
R20: 390; R_0402_1005Metric; Manufacturer Part 0402WGF3900TCE
R23: 10R; R_0402_1005Metric; Manufacturer Part 0402WGF100JTCE
RESET1: GT-TC029B-H025-L1N; SW_Push_GSwitch_GT-TC029B; Manufacturer Part GT-TC029B-H025-L1N
SD-CARD1: TF-015; microSD_ATOM_MR01A-01211; Manufacturer Part TF-015
SPI1: HDR-M-2.54_1x3; PinHeader_1x03_P2.54mm_Vertical; Manufacturer Part 2.54mm 1x3 header
U1: ESP32-S3-WROOM-1(N16R8); ESP32-S3-WROOM-1_RejsaCAN; Manufacturer Part ESP32-S3-WROOM-1-N16R8
U2: SN65HVD230DR; SOIC-8_RejsaCAN_5.544mm; Manufacturer Part SN65HVD230DR
U3: ME2807A33M3G; SOT-23; Manufacturer Part ME2807A33M3G
U4: LMR51610XDBVR; TSOT-23-6; Manufacturer Part LMR51610XDBVR
U5: MT9700; SOT-23-5; Manufacturer Part MT9700
U6: AQY212GS; SOP-4_3.8x4.1mm_P2.54mm; Manufacturer Part AQY212GS
U7: LG290P03AAMD; Manufacturer Part LG290P03AAMD
U8: RT9013-33GB; SOT-23-5; Manufacturer Part RT9013-33GB
USBC1: GT-USB-7010ASV; USB_C_Receptacle_GT-USB-7010ASV_MergedPins; Manufacturer Part GT-USB-7010ASV
YELLOW1: 19-213/Y2C-CQ2R2L/3T(CY); LED_0603_1608Metric; Manufacturer Part 19-213/Y2C-CQ2R2L/3T(CY)

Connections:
3V3: C1.1, C2.2, C4.2, C8.2, C9.2, C10.2, C11.2, C33.2, GREEN1.1 (A), I2C1.1, L1.2, R1.2, R9.2, R17.2, SD-CARD1.4 (VDD), U1.2 (3V3), U2.3 (VCC), U5.5 (VIN), U8.1 (VIN), U8.3 (EN)
3V3_SWITCHED: C12.2, GPIO1.1, U5.1 (VOUT)
BLUE_LED: BLUE1.1 (A), U1.18 (IO10)
CAN_H: J1.3, U2.7 (CANH), U6.4
CAN_L: J1.4, R2.1, U2.6 (CANL)
CAN_RS: R3.2, U1.31 (IO38), U2.8 (RS)
CAN_RX: U1.21 (IO13), U2.4 (R)
CAN_TX: U1.22 (IO14), U2.1 (D)
FORCE_ON: D2.2 (A), U1.10 (IO17)
GND: C1.2, C2.1, C3.1, C4.1, C5.1, C6.1, C8.1, C9.1, C10.1, C11.1, C12.1, C13.1, C27.1, C28.1, C29.1, C31.1, C32.1, C33.1, D4.2, D5.2 (A), D8.2, D10.2, D11.2, D13.1, GPS1.2 (C), I2C1.2, J1.2, J2.2, J3.2, PROG1.2, R3.1, R5.1, R6.1, R7.1, R8.1, R10.2, R11.1, R12.1, R13.1, R14.2, R15.2, R16.1, R19.2, R21.1, RESET1.2, SD-CARD1.6 (VSS), SD-CARD1.10 (GND), SD-CARD1.11 (GND), SD-CARD1.12 (GND), SD-CARD1.13 (GND), U1.1 (GND), U1.4 (IO4), U1.5 (IO5), U1.40 (GND), U1.41 (GND), U2.2 (GND), U3.2 (GND), U4.2 (GND), U5.2 (GND), U6.2, U7.10 (GND_1), U7.12 (GND_1__1), U7.13 (GND_1__2), U7.24 (GND_1__3), U7.25 (GND_1__4), U7.26 (GND_1__5), U7.27 (GND_1__6), U7.28 (GND_1__7), U7.29 (GND_1__8), U7.30 (GND_1__9), U7.31 (GND_1__10), U7.32 (GND_1__11), U7.33 (GND_1__12), U7.34 (GND_1__13), U7.35 (GND_1__14), U7.36 (GND_1__15), U7.37 (GND_1__16), U7.38 (GND_1__17), U7.39 (GND_1__18), U7.40 (GND_1__19), U7.41 (GND_1__20), U7.42 (GND_1__21), U7.43 (GND_1__22), U7.44 (GND_1__23), U7.45 (GND_1__24), U7.46 (GND_1__25), U7.47 (GND_1__26), U7.48 (GND_1__27), U7.49 (GND_1__28), U7.50 (GND_1__29), U7.51 (GND_2), U7.52 (GND_2__1), U7.53 (GND_2__2), U7.54 (GND_2__3), U7.55 (GND_2__4), U7.56 (GND_2__5), U7.57 (GND_2__6), U7.58 (GND_2__7), U7.59 (GND_2__8), U7.60 (GND_2__9), U7.61 (GND_2__10), U7.62 (GND_2__11), U7.63 (GND_2__12), U7.64 (GND_2__13), U7.65 (GND_2__14), U7.66 (GND_2__15), U7.67 (GND_2__16), U7.68 (GND_2__17), U7.69 (GND_2__18), U7.70 (GND_2__19), U7.71 (GND_2__20), U7.72 (GND_2__21), U7.73 (GND_2__22), U7.74 (GND_2__23), U7.75 (GND_2__24), U7.76 (GND_2__25), U7.77 (GND_2__26), U7.78 (GND_2__27), U7.79 (GND_2__28), U8.2 (GND), USBC1.1 (SHELL), USBC1.2 (SHELL), USBC1.3 (SHELL), USBC1.4 (SHELL), USBC1.A1B12 (GND), USBC1.B1A12 (GND)
GNSS_ANT: C30.1, D13.2, J2.1, L2.2
GNSS_BIAS: C29.2, C31.2, L2.1, R23.2
GNSS_LED: GPS1.1 (A), R22.2
GNSS_RF_IN: C30.2, U7.11 (RF_IN)
GNSS_VCC: C27.2, C28.2, C32.2, U7.22 (V_BCKP), U7.23 (VCC), U8.5 (VOUT)
GNSS_VDD_RF: R23.1, U7.9 (VDD_RF)
GPIO6: U1.6 (IO6), U7.3 (1PPS)
GPIO7: U1.7 (IO7), U7.8 (~RESET)
GPIO12: GPIO1.4, U1.20 (IO12)
GPIO47: GPIO1.2, U1.24 (IO47)
GPIO48: GPIO1.3, U1.25 (IO48)
GPS_LOCK: R22.1, U1.8 (IO15), U7.14 (RTK_STAT/ANT_ON)
HI_DRIVER: U1.23 (IO21), U5.4 (EN)
JTAG_ENABLE: U1.15 (IO3)
MTCK: SD-CARD1.5 (CLK), SPI1.2, U1.32 (IO39)
MTDI: R17.1, SD-CARD1.7 (DAT0), SPI1.3, U1.34 (IO41)
MTDO: SD-CARD1.3 (CMD), SPI1.1, U1.33 (IO40)
MTMS: U1.35 (IO42)
unnamed: BLUE1.2 (C), R14.1
unnamed: D1.1 (K), D9.2 (A), Q1.2 (E), R7.2
unnamed: D2.1 (K), D3.1 (K), D9.1 (K), JUMPER1.1, R8.2, U4.4 (SHDN#)
unnamed: C7.1, D5.1 (K), L1.1, U4.6 (SW)
unnamed: D6.1 (K), D7.1 (K), F1.2
unnamed: GREEN1.2 (C), R13.2
unnamed: Q1.1 (B), U3.1 (VOUT)
unnamed: R20.2, U6.1
unnamed: C3.2, R1.1, RESET1.1, U1.3 (EN)
unnamed: C5.2, R4.1, R5.2, R19.1, U3.3 (VIN)
unnamed: C7.2, U4.1 (CB)
unnamed: R9.1, R10.1, U4.3 (FB)
unnamed: R16.2, U5.3 (SET)
unnamed: R11.2, USBC1.A5 (CC1)
unnamed: R12.2, USBC1.B5 (CC2)
unnamed: R15.1, YELLOW1.2 (C)
PROG: PROG1.1, U1.27 (IO0)
RXD: U1.36 (RXD0), U7.20 (TXD1)
SCL: I2C1.3, U1.38 (IO2)
SDA: I2C1.4, U1.39 (IO1)
SD_CARD: SD-CARD1.2 (CD/DAT3), U1.26 (IO45)
SENSE_V_ANA: R6.2, R18.1, U1.17 (IO9)
SENSE_V_DIG: D1.2 (A), U1.12 (IO8)
TERM_EN: R20.1, R21.2, U1.9 (IO16)
TERM_SW: R2.2, U6.3
TXD: U1.37 (TXD0), U7.21 (RXD1)
USB_D+: D10.1, J3.4, U1.14 (IO20), USBC1.A6 (DP1), USBC1.B6 (DP2)
VCC: C6.2, C13.2, F1.1, JUMPER1.2, Q1.3 (C), R4.2, R18.2, U4.5 (VIN)
YELLOW_LED: U1.19 (IO11), YELLOW1.1 (A)

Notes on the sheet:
ALWAYS ON
JUMPER

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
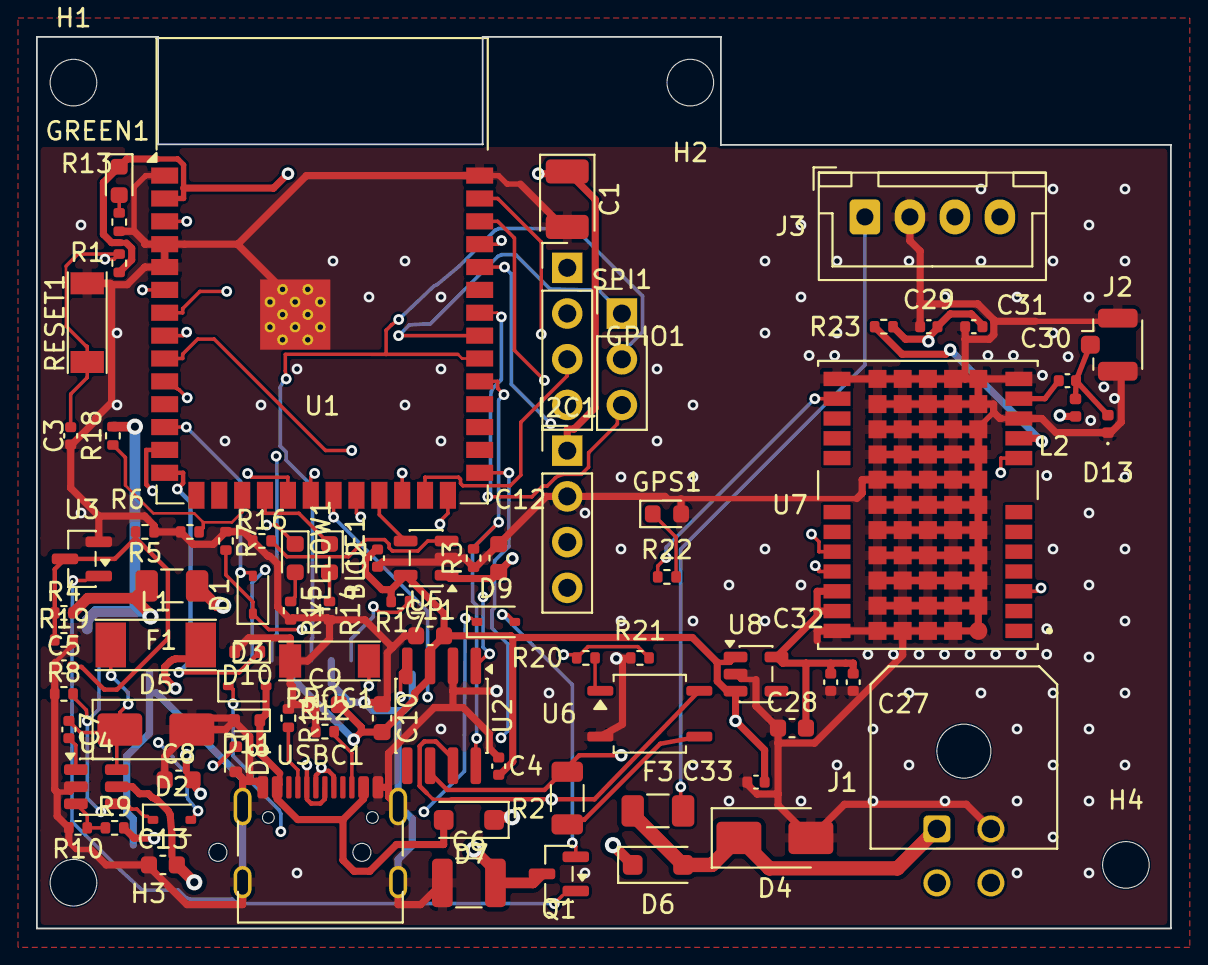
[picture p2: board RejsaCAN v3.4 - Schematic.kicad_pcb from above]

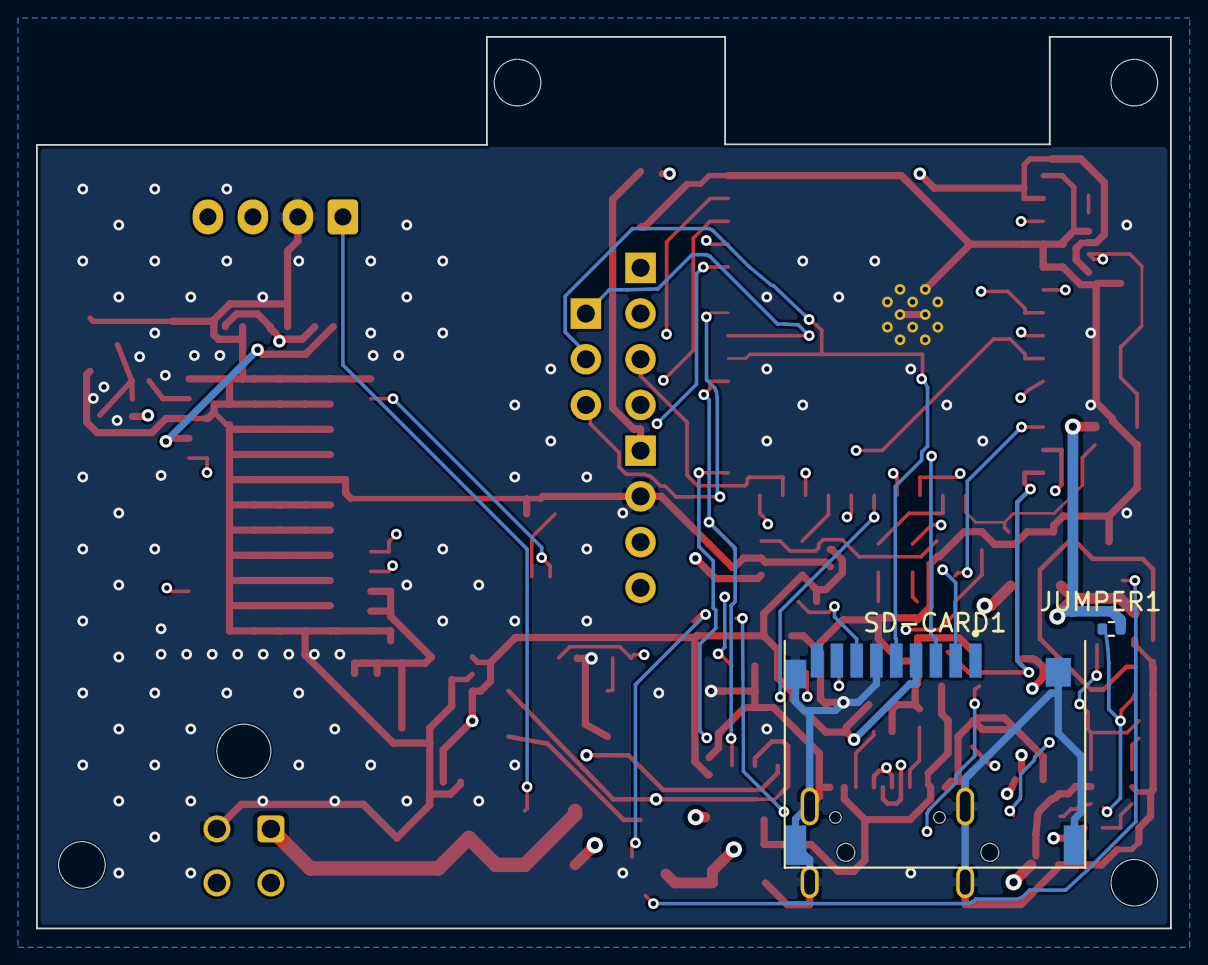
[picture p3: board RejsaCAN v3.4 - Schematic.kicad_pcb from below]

Board: 4 copper layers, 63.0 x 49.5 mm, 87 parts (2 on the bottom side), 59 nets.

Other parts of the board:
H1, H2, H3, H4: MountingHole_2.59mm_NPTH

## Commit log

2026-05-16 Add RejsaCAN v3.4 schematic and converter
    Add Eagle schematic for RejsaCAN v3.4 (ESP32-S3 based board) and a converter toolchain. Includes the .sch file and a converter directory with convert.py, easyeda_parser.py, eagle_emitter.py and a REA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
    [RejsaCAN v3.4.sch]
2026-08-15 Add KiCad 10 project for RejsaCAN v3.4, derived from EasyEDA source
    The repo has never carried a PCB layout source for any board generation --
    only EasyEDA schematic JSON plus Gerber output. This adds a native KiCad
    project so the v3.4 board can actually be edited, re-laid out and fabbed.
    Schematic: imported from "RejsaCAN v3.4 - Schematic.json", annotated
    (letter-only designators gained numbers, e.g. CAN -> CAN1, so they differ
    from the fabricated board's silkscreen), and the EasyEDA drawing-frame
    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
    [RejsaCAN v3.4 - Schematic.kicad_pcb, RejsaCAN v3.4 - Schematic.kicad_sch]
2026-08-15 Add v3.4 board outline and mounting holes, traced from the fabricated Gerbers
    The KiCad board had no Edge.Cuts geometry at all, which blocks placement,
    routing and any real fab quote (board price is a function of dimensions).
    Both the outline and the holes are derived from upstream manufacturing data
    rather than drawn by eye:
    Gerber_BoardOutlineLayer.GKO -> 8-corner Edge.Cuts profile
    Drill_NPTH_Through.DRL, T03 -> four 2.59mm NPTH mounting holes
    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
    [RejsaCAN v3.4 - Schematic.kicad_pcb]
2026-08-15 Update CLAUDE.md for the board outline, mounting holes and DRC rule mismatch
2026-08-16 Recover the original v3.4 component placement, and set JLCPCB/automotive rules
    Placement is reconstructed from the fabricated board's own manufacturing data
    rather than laid out afresh, because the mechanical constraints are fixed: the
    connectors must meet the board edges and the 3D-printed cases in this repo are
    cut for the original positions.
    Method, in decreasing order of certainty:
    1. The solder-mask layers give the complete pad cloud (paste is no good --
    the original skips it for hand-soldered parts). Distinctive multi-pad
    footprints are matched to it by hypothesising rotation and translation,
    most-pads-first so a TSOT-23-6 cannot settle onto 6 of a SOIC-8's pads.
    2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
    [RejsaCAN v3.4 - Schematic.kicad_pcb]
2026-08-16 Correct three footprints to the land patterns actually fabricated
    Measured from the v3.4 manufacturing data -- top-copper flashes for the pads,
    the NPTH drill file for the board locks -- rather than trusted from the stock
    libraries:
    F1 pad pitch 3.706mm and 1.407 x 3.500 pads; KiCad's 1812 land is 4.276mm
    U2 SOIC-8 rows 5.544mm apart with 2.045 x 0.588 pads, not 4.95 / 1.95x0.60
    USBC1 shell legs 1.067 and 5.267mm below the contact row (library said 0.600
    and 4.800); NPTH board locks 1.676mm below it (library said 1.120)
    All three now sit on their original pads to 0-1 um, and board pad coverage rises
    from 216 to 225 of 232. F1 and U2 move to project-local footprints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
    [RejsaCAN v3.4 - Schematic.kicad_pcb, RejsaCAN v3.4 - Schematic.kicad_sch]
2026-08-16 Route the v3.4 board: 555 tracks, 116 vias, ground pours both layers
    DRC is clean of every electrical class: no shorts, no clearance violations, no
    mask bridges, no dangling ends, no hole-spacing or annular problems, and zero
    schematic-parity errors. 16 connections remain open (see below).
    The autorouter is driven with settings taken from Freerouting's own docs rather
    than guessed, which changed the outcome substantially:
    --gui.enabled=false the NullPointerException that fired on every
    previous run was in ConductionArea's *paint*
    path, not the router; headless never hits it
    --router.optimizer.enabled=false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
    [RejsaCAN v3.4 - Schematic.kicad_pcb]
2026-08-16 Widen two auto-neckdown tracks to keep the 5 mil economical tier
    Freerouting's automatic neckdown left two short Net-(D2-K) segments at 0.1mm
    (3.9 mil), under JLCPCB's 5 mil economical threshold -- enough to push the whole
    board into the fine-feature process. Widened to 0.15mm; minimum trace is now
    5.9 mil and DRC stays clean of every electrical and fabrication class.
    [RejsaCAN v3.4 - Schematic.kicad_pcb]
2026-08-16 Enlarge U1's thermal vias to 0.3mm, clearing the last sub-tier feature
    The stock ESP32-S3-WROOM-1 footprint drills its 12 thermal vias at 0.2mm, the
    only feature left under JLCPCB's economical thresholds. Smallest drill on the
    board is now 0.300mm, so both limits are satisfied: 5.9 mil minimum trace and
    0.3mm minimum hole.
    My earlier worry that this would trade one problem for another was based on a
    mis-estimated pitch, read off rounded DRC coordinates. Measured properly the
    vias sit on a 0.99mm pitch, so a 0.3mm drill still leaves a 0.69mm hole-to-hole
    gap against JLCPCB's 0.45mm guidance -- no trade-off at all.
    Only the drill changed. Growing the pad to 0.7mm as well (for a wider annular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
    [RejsaCAN v3.4 - Schematic.kicad_pcb, RejsaCAN v3.4 - Schematic.kicad_sch]
2026-08-17 Update CLAUDE.md for the routed board, and record what this session learned
    Corrections, which matter more than the additions -- the file claimed the board
    was unrouted and that the thermal vias still needed fixing, both false since:
    routed board status with the 16 connections deliberately left open, three custom
    DRU rules, eight project-local footprints (three corrected to the fabricated land
    patterns), and the obsolete drill_out_of_range gotcha removed.
    New sections cover what took this session longest to rediscover:
    Scripting the board -- KiCad's bundled Python is the only one with pcbnew;
    kicad-cli pcb drc is the only real judge, since the Python API exposes no DRC
    engine or rout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
2026-08-17 Schematic: Micro-Fit input connector and software-switched CAN termination
    Replaces the two 2.54mm headers with a single 4-circuit connector, and
    turns the cuttable termination link into a GPIO-controlled photorelay.
    J1 (Molex Micro-Fit 3.0 43045-0400, 2x02 right-angle) carries 12V, GND,
    CAN_H and CAN_L, superseding POWER1 and CAN1. Pins 1 and 2 land on the
    existing 12V and GND wires, so the input protection chain is untouched.
    Termination was R2 wired permanently across the bus, opened only by
    cutting the copper link between TERMINATION1's two pads. U6 (CPC1018N
    photorelay) now sits in that gap: CAN_H -> U6 -> TERM_SW -> R2 -> CAN_L.
    The photorelay is bipolar and optically isolated, so t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
    [RejsaCAN v3.4 - Schematic.kicad_sch]
2026-08-17 Schematic: add LG290P03 GNSS receiver, u.FL antenna and lock LED
    U7 is a Quectel LG290P (03) quad-band RTK GNSS module (12.2 x 16.0 x
    2.6 mm, 79 pads), talking to the ESP32-S3 over the second UART that
    upstream had reserved but never connected.
    Connections, all on pins that were previously unused:
    TXD1/RXD1 <-> RXD/TXD (GPIO44/43) -- module I/O follows VCC, so
    3.3V logic throughout, no level shifting
    1PPS -> GPIO6
    ~RESET <- GPIO7
    RTK_STAT -> GPS_LOCK: drives GPS1 via R22 1k, and is readable on
    GPIO15 so firmware can see fix state
    VCC/V_BCKP <- 3V3, decoupled by C27 100nF + C28 22uF
    Antenna is an external active type fe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
    [RejsaCAN v3.4 - Schematic.kicad_sch]
2026-08-17 Correct the GNSS front end against Quectel's reference circuit
    The bias tee and decoupling were provisional standard values. Checked
    against LG290P(03) Hardware Design V1.1 section 5.2 / Figure 17 and
    corrected to match it component-for-component.
    L2 27nH -> 68nH Quectel: "at least 68 nH". 27nH gave only ~200
    ohm of isolation at the bottom of the L5/B2a band
    R23 10R new series in VDD_RF; Quectel's stated protection for
    an active antenna shorted to the ground plane
    C31 100pF new bias-node bypass, pairs with C29 100nF per Fig.17
    C32 33pF new completes the 22uF/100nF/33pF VCC network; the
    smalles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
    [RejsaCAN v3.4 - Schematic.kicad_sch]
2026-08-17 PCB: 4 layers, 58mm-wide outline, all new parts placed and netted
    Board rebuilt to carry the GNSS block. NOT ROUTED and placement is not
    final -- see the caveats below before doing anything with this.
    Done:
    - outline widened 31.5 -> 58.1 mm; H2/H4 moved out to the new right
    edge. Height and the top notch are unchanged, so USB-C and the
    other bottom-edge parts keep their edge.
    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
    [RejsaCAN v3.4 - Schematic.kicad_pcb]
2026-08-17 Uprate the 3V3 supply for the GNSS load; retarget the photorelay
    Adding the LG290P pushed the 3V3 rail past its regulator. Measured
    against datasheets rather than estimated:
    ESP32-S3 802.11b TX @20.5dBm 355 mA DS v1.8 T6-4
    LG290P acquisition and tracking 135 mA HW Design Table 11
    active antenna LNA via VDD_RF 30 mA
    SN65HVD230 dominant, 60R 70 mA SLOS346O
    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
    [RejsaCAN v3.4 - Schematic.kicad_sch]
2026-08-17 Update CLAUDE.md for the v3.5 branch, and correct stale ordering facts
    The KiCad section described a 2-layer 31.5mm board that no longer
    exists on this branch. Rewritten to cover the 58.1 x 49.63 mm 4-layer
    state, the three new blocks, and the two problems that block routing:
    the U1/U7 antenna keep-out overlap, and Quectel forbidding a switching
    supply on the module.
    Three ordering facts recorded here were wrong or incomplete:
    - The $3.12 Global Standard Direct Line rate is gone for US
    individual customers, who must now ship DDP via express only.
    DHL DDP is ~$28.57.
    - A 55% tariff is pre-collected on FR-4 PCBs from 17 March 2026.
    - 4-layer has a 50x50mm tier boundary: under i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
2026-08-17 Dedicated LDO for the GNSS, and an L-shaped bump-out instead of a wide board
    Two changes asked for: give the GNSS its own regulator, and stop
    widening the whole board just to fit the module.
    LDO
    ---
    FB1's ferrite pi filter is gone; U8 (AP2112K-3.3, SOT-23-5, 600 mA)
    now feeds GNSS_VCC from 3V3, EN tied high, with C33 1uF on the input.
    This satisfies Quectel's "do not use a switching DC-DC converter",
    which the ferrite only softened.
    It does not work as a straight drop-in, though, and that is the part
    worth recording: the buck was set to 3.29 V and the module wants 3.3 V,
    so any 3.3 V LDO fed from it would sit in dropout, where PSRR collapses
    and the LDO filters nothing at all. So R9 goes 3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
    [RejsaCAN v3.4 - Schematic.kicad_pcb, RejsaCAN v3.4 - Schematic.kicad_sch]
2026-08-17 Add J3, the LTE breakout: raw 12V, GND, USB_D- and USB_D+
    The LTE module talks to the ESP32 over USB rather than UART, so J3
    parallels the native USB pair and splits the input 12V off to feed the
    module.
    J3.1 VBAT_IN raw 12V, tapped at J1.1 ahead of D6 and F1
    J3.2 GND
    J3.3 USB_D- GPIO19
    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
    [RejsaCAN v3.4 - Schematic.kicad_pcb, RejsaCAN v3.4 - Schematic.kicad_sch]
2026-08-17 Route the v3.5 board: 882 tracks, 85 vias, GND poured on three layers
    DRC is clean of every electrical and fabrication class -- no shorts, no
    clearance violations, no crossings, no solder-mask bridges, no starved
    thermals, no annular-ring or board-edge errors. Five connections remain
    open, all in the power corner; finish them in the GUI's interactive
    router, which can shove existing traces where the Python API cannot.
    F.Cu 813.7 mm
    PWR_plane 762.1 mm
    B.Cu 296.4 mm
    GND_plane 0 mm -- held solid on purpose
    Routing took three Freerouting runs and the first two taught us things.
    Run 1 (12 unrouted): I had raised the Battery net class to 0.8mm wide
    and 0.6mm clearance, qu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
    [RejsaCAN v3.4 - Schematic.kicad_pcb]
2026-08-17 Act on the design-rule audit: antenna keepout, input trace, RF stubs
    A 7-agent audit checked this board's rules against published sources and
    probed the board file. It found things that would have shipped.
    A8 -- MY DEFECT, the serious one. Going to 4 layers did not extend the
    antenna keep-outs, which still listed F.Cu/B.Cu from the 2-layer era, so
    the new In1 plane flooded 97 mm2 of solid copper about 0.21 mm under the
    ESP32-S3's PCB antenna. That detunes it. Keep-out now covers all four
    layers; verified 0/280 sample points filled where it was solid before.
    Corollary caught on the way: I first extended J2's keep-out the same way,
    which was wrong. U1 is a radiating antenna and needs all-lay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
    [RejsaCAN v3.4 - Schematic.kicad_pcb]
2026-08-17 Correct the IPC-2221 guidance in CLAUDE.md, and record two hard-won rules
    The "raise Battery spacing to 0.6mm on the 4-layer respin" note in this file
    was wrong and cost two routing attempts before it was caught. IPC-2221
    table 6-1 is indexed by COATING, not by layer:
    B1 internal 0.10mm
    B2 external, uncoated 0.60mm
    B4 external, solder mask 0.13mm <- this board
    A6 external uncoated terminations 0.50mm at 51-100V (bare pads)
    Every track here is masked, so B4 applies and 0.35mm already carries 2.7x
    margin. 0.6mm is column B2. It was tried on 4 layers as the note advised and
    made the power corner unroutable for no electrical gain. Re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
2026-08-17 Front end rated for real automotive transients: 5-24V, 33V ceiling
    The board claimed 5-24V but none of its three protection devices supported it.
    Owner confirmed the operating reality -- a 12V system running at 14V with
    spikes -- and confirmed the installation constraint the fix depends on.
    The chain that sets the rating: a 12V-system SUPPRESSED load dump is 35V for
    40-400ms, so the clamp must not conduct at 35V -> 33V standoff -> VC 53.3V at
    25C, ~56V hot -> the regulator must survive ~56V. That single requirement
    forces every part below.
    U4 LMR14010A -> LMR51610X 45V abs max could not take any clamp that
    survives a 35V dump. Same SOT-23-6 land.
    R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
    [RejsaCAN v3.4 - Schematic.kicad_sch]
2026-08-18 PCB: rebuild for the new front end, spread the power corner, re-route
    DRC clean of every electrical and fabrication class. 4 connections open, all
    in the power section; finish them in the GUI's interactive router, which can
    shove existing traces where the Python API cannot.
    947 tracks, 80 vias, 87 footprints
    PWR_plane 875.2 mm
    F.Cu 872.7 mm
    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
    [RejsaCAN v3.4 - Schematic.kicad_pcb, RejsaCAN v3.4 - Schematic.kicad_sch]
2026-08-18 CLAUDE.md: bring the board state current, record the routing method
    Audited this file against the repo. Commands and the design-source model held
    up; currency did not. It described a state two commits and a full rebuild old,
    and it misled in ways that would cost a future session real time:
    - said "all routing stripped, not re-routed" when the board is routed and
    DRC clean
    - listed two problems as blocking that are both closed (the bump-out cleared
    the WROOM antenna keep-out; U8 replaced the ferrite compromise)
    - named U4 as LMR14010A, six parts and a whole front-end re-rating out of date
    - undercounted the net classes (6 -> 8) and the custom rules (3 -> 5)
    Added, all of it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
2026-08-18 PCB: finish routing (0 unconnected), stitch ground, clean courtyards; DRC 0 errors
    Routing: the last 4 open connections are closed by a scripted obstacle-aware
    grid router (per-layer clearance-inflated raster, Dijkstra over F/In2/B with
    via transitions), each route accepted only when kicad-cli DRC did not rise.
    - Net-(Q1-B): B.Cu down the left edge and along the bottom, 2 vias.
    - 3V3 module island (U1.2/GREEN1/R1): F -> In2 under the module -> C1.
    - Net-(D6-K): D7 rotated 180 so its cathode faces the free F.Cu toward the
    existing D6-K via; USB5V re-stubbed straight down onto its track.
    - VCC -> U4.5: EN (Net-(D2-K)) and FORCE_ON stripped, the 3V3 F.Cu feed
    from L1.2 removed, VCC routed F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
    [RejsaCAN v3.4 - Schematic.kicad_pcb]
2026-08-18 PCB: relocate reference designators off pads and edges (silk warnings 203 -> 149)
    [RejsaCAN v3.4 - Schematic.kicad_pcb]
2026-08-18 PCB: move SPI1 (MTDO/MTCK/MTDI) out from under the WROOM into the header area
    The recovered v3.4 placement had put the 3-pin SPI/JTAG header on three of
    upstream's rear-access pads under the module (upstream's README: those pads
    carry GPIO6/7/15/16, MTMS, PROG, JTAG_ENABLE, TXD0, RXD0 and have no
    symbols, so they never entered this netlist; MISO/CLK/MOSI belong in the
    header row). A header nobody can populate is a defect, so SPI1 now sits as a
    second column beside GPIO1 (X 142.5, pins at 195.37/197.91/200.45), ~8 mm
    from U1's MTDx pads, re-routed on B.Cu; the old under-module stubs are gone.
    DRC: 0 errors, 0 unconnected.
    [RejsaCAN v3.4 - Schematic.kicad_pcb]
2026-08-18 CLAUDE.md + tools: record the finished board, the router that closed it, and the quote
    - CLAUDE.md: board state (0 unconnected, DRC 0 errors, 98 stitching vias, which
    warnings remain and why), how the last four connections were actually closed
    (scripted grid router + DRC gate, after two placement fixes), the SPI1
    relocation and its cause, Freerouting 2.3.0 findings (autoroute_settings
    block breaks the parse, --router.fanout.enabled=false, protect-mode loads
    79 unrouted), and the 18 Aug JLCPCB quote ($7.00/5 + $28.57 DDP).
    - KiCad/tools/: miniroute.py, stitch.py, drcgate.py with a README, paths made
    repo-relative; tools/out/ gitignored.
    - fabrication/README.md: 4-layer Gerber/dril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
2026-08-18 PCB: sync 7 stale footprint Value fields from the schematic (U4/U6/L1/R9/R10/R20/D5)
    [RejsaCAN v3.4 - Schematic.kicad_pcb]
2026-08-18 CLAUDE.md: assembly cost estimate (JLC fee structure + LCSC prices), BOM sourcing gaps
2026-08-18 BOM: verified, stocked LCSC part on every line; equivalents for the unstocked ones
    Every symbol now carries Manufacturer Part / Manufacturer / Supplier Part
    (LCSC C-number) checked against LCSC stock on 2026-08-18. Land patterns of
    the substitutes were compared numerically (EasyEDA footprint API) where the
    package mattered:
    - SD-CARD1: ATOM MR01A-01211 (C479742, out of stock) -> SOFNG TF-015
    (C113206): identical TF-015-family land within 0.1 mm incl. the two 1.0 mm
    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
    [RejsaCAN v3.4 - Schematic.kicad_pcb, RejsaCAN v3.4 - Schematic.kicad_sch]
2026-08-18 CLAUDE.md: BOM is JLC-ready; record the substitutions and the EasyEDA footprint-API trick
2026-08-18 Schematic: reorganize so nothing overlaps; connectivity verified identical
    The scripted-in sections had been dropped on top of each other: D4 on the
    USB-C CC resistors, J3 on the USB-C connector, the whole GNSS/LDO/bias-tee
    set crammed into a 118x41 mm strip with labels crossing parts, D13 on C33,
    TERM_EN labels through R20/R21, J1's GND flag under the CAN labels, and
    ~150 reference/value texts on neighbouring parts.
    Method (all scripted, tools in the session scratchpad):
    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
    [RejsaCAN v3.4 - Schematic.kicad_sch]
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
